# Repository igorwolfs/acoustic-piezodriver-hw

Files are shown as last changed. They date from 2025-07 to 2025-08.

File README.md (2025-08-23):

# Acoustic Piezodriver HW

This board generates the signal used to excite the piezo-module. Excitation frequencies are between 100 kHz and 10 MHz. All above 5 MHz will probably be hard to reach, given the component specs had to be balanced with price.

## 40V BOOST
Supplies the single-phase inverter with a 40 V voltage, given a 20 V input voltage.

## 6V SEPIC
Supplies around 6 V to the PCONN 5V connector. Meant to supply power to the acoustic-processing-hw board.

## 10 V SEPIC
Supplies the FET-drivers with a steady 10V.

## SIGCONN
Drives the PWM signals, enables the 40V BOOST and the 10V SEPIC, contains an SPI bus meant to control the on-board ADC and temperature sensors. Meant to be connected to the acoustic-processing-hw board.

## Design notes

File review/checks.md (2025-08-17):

# Component Checks
## I2C bus connection
- Are all I2C bus signals connected to the output

## Footprints
- Are all footprints
	- Corresponding to the footprint in the datasheet
	- Is the actual component the right one (right capacitance / resistance / LCSC PN)

## Temperature Sensor
- Check the plane requirements below the sensor.

## Connectors
- Check connector orientation 
- Check connector distance from edge
- Check connector footprint

## Footprints
- Check whether footprints 

# Capacitors
## C1 / C2 bootstrap caps
- 220 nF OK -> 
-

## Filtering caps
- 220 nF? Why so large?

# IC's
## Switching IC
10 V sepic
- Impedance: 39 kOhm

# Layout Checks
## Positioning 
- Check whether feedback resistors for DC-DC converters are easily replaceable if needed
- Check if there's measurement points at the input

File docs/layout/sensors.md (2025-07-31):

# Temperature sensor

- Put a copper plane between the heat-source and draw it until underneath the sensor

# ADC
- Make sure the traces between the HAL-sensors and the ADC are not routed across a too noisy area.
	- Although impedance is honestly pretty low

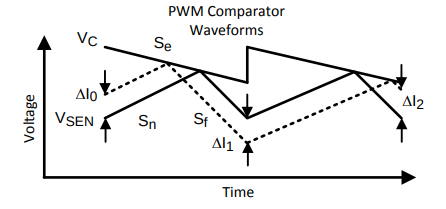
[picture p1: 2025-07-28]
docs/schematic/dcdc-converters/images/LM3478_subharmonic.png

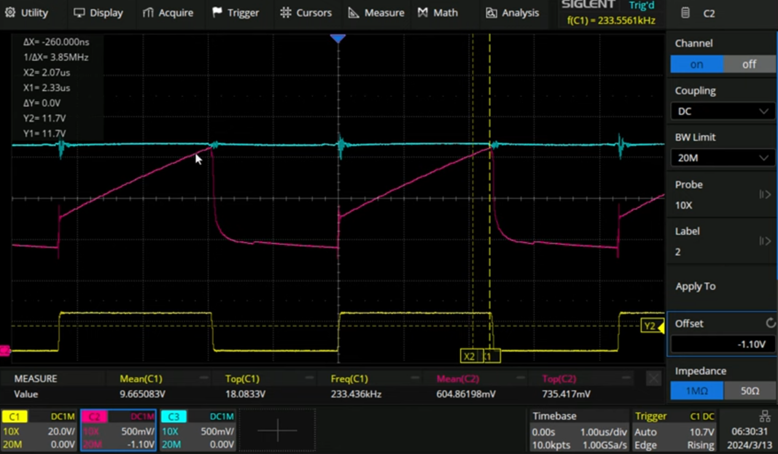
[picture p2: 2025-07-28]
docs/schematic/dcdc-converters/images/peak_current_mode_control.png

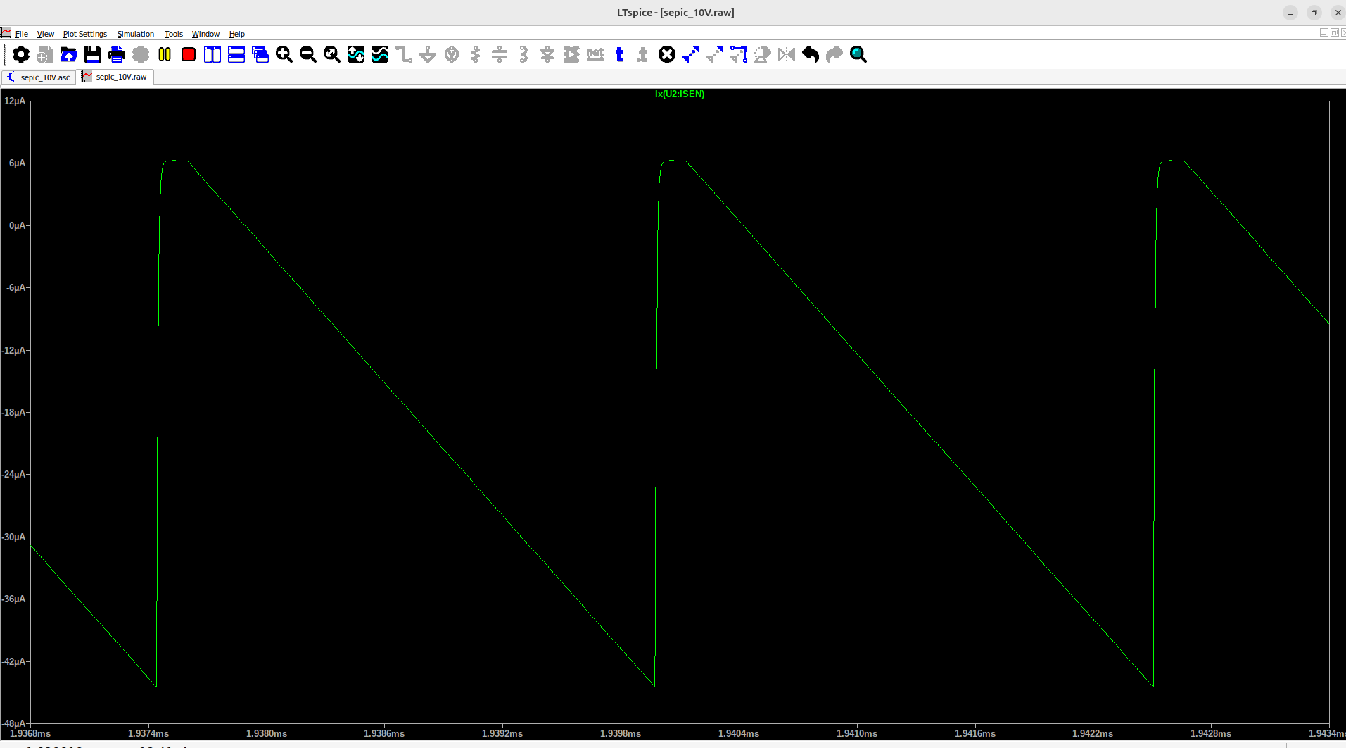
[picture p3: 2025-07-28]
docs/schematic/dcdc-converters/images/LM3478_Isense_nocomp.png

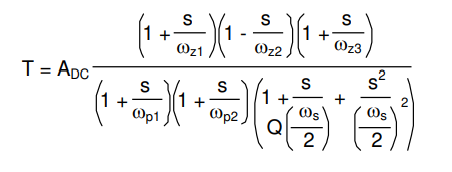
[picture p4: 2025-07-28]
docs/schematic/dcdc-converters/boost_converter/control_tot.png

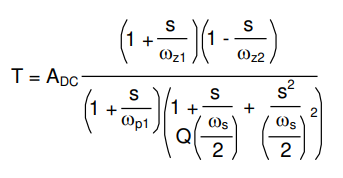
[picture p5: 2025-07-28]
docs/schematic/dcdc-converters/boost_converter/control_co.png

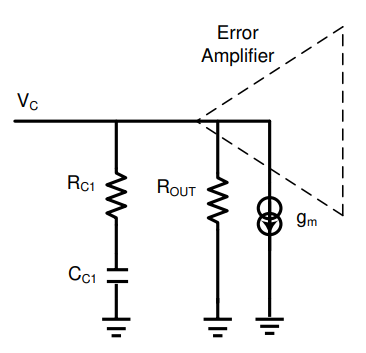
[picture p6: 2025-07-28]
docs/schematic/dcdc-converters/boost_converter/control_ea.png

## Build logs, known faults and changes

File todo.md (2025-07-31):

# Schematics
## DC-DC Converters
- Add 1 x LM3478 (doesn't require level-shifting circuitry)
	- Boost converter: to bring a voltage of between 15-20 volts up to 40 V ()
- Add 1 x SEPIC converter for the level-shifting FET drivers
- Add 1 x SEPIC-converter for the 5 V power supply

### Goal
- We want to be able to adapt the driving voltage dynamically
	- The boost converter will need to drive the voltage to up to 40 volts
		- It however might have 9-10 volts connected
		- There should be a bypass from the boost converter VBAT directly to the inverted driving circuit as well
			- This way we can drive the piezo with voltages as low as 5 Vpp
	- The level shifter will need to continuously be at 10 volts.
		- It however might have 9-10 V connected
- We want to avoid working with variable resistors

#### Boost converter (5-20 V -> 5-40 V)
- Input: between 5 and 20 volts
	- If < 10 volts: make sure you have bypass circuitry that allows you to directly drive the inverter from your source
	- If > 10 volts: make sure you have some-kind of soldering bridge or short that you can eliminate to force all current through the boost converter.
		- Add a spot for a feedback resistor slope compensation (in case D > 0.5)
- Output: between 5 V and 40 V
- Currents: max 10 amps RMS at 40 V

**Bypass** 
- Create a bypass for the boost converter (e.g.: simply 0-ohm high power resistor, or solderbridge) whenever you want to use pure battery voltage
- When you want to use a voltage unreachable by your power supply (e.g.: 40 V)
	- Make sure to use a boost converter, and set the input voltage between 10-20 Volts (to limit the stress on the passives)

## ADC Measurement
- Add a 4-channel ADC 
	- (2 inputs) Differential channel to measure current going to the piezo
	- 1 input: Current going to the ADC
	- 1 input: Total voltage (use a resistive divider)
		- Based on this one can activate SEPICs
	- 1 input: Total current draw (use a resistor)
- Add front-end (RC-filter at cutoff below 1 kHz for noise purpoes)
- Add hall-sensor for in-circuit current measurement
- Add a voltage divider so 
	- Vbat: (0, 25) -> (0->2.048)

## Temperature Sensors
- 2 different addresses
- Communication over I2C

## I2C bus checks
- Check if total capacitance on the I2C bus isn't too large
- I2C ADC-bus
- 2xI2C temperature sensors

## Connectors
- Add pads for each power supply so you can supply it externally for testing if necessary
	- For 6V no pad is required since there is already a hal-sensor that takes in the current.

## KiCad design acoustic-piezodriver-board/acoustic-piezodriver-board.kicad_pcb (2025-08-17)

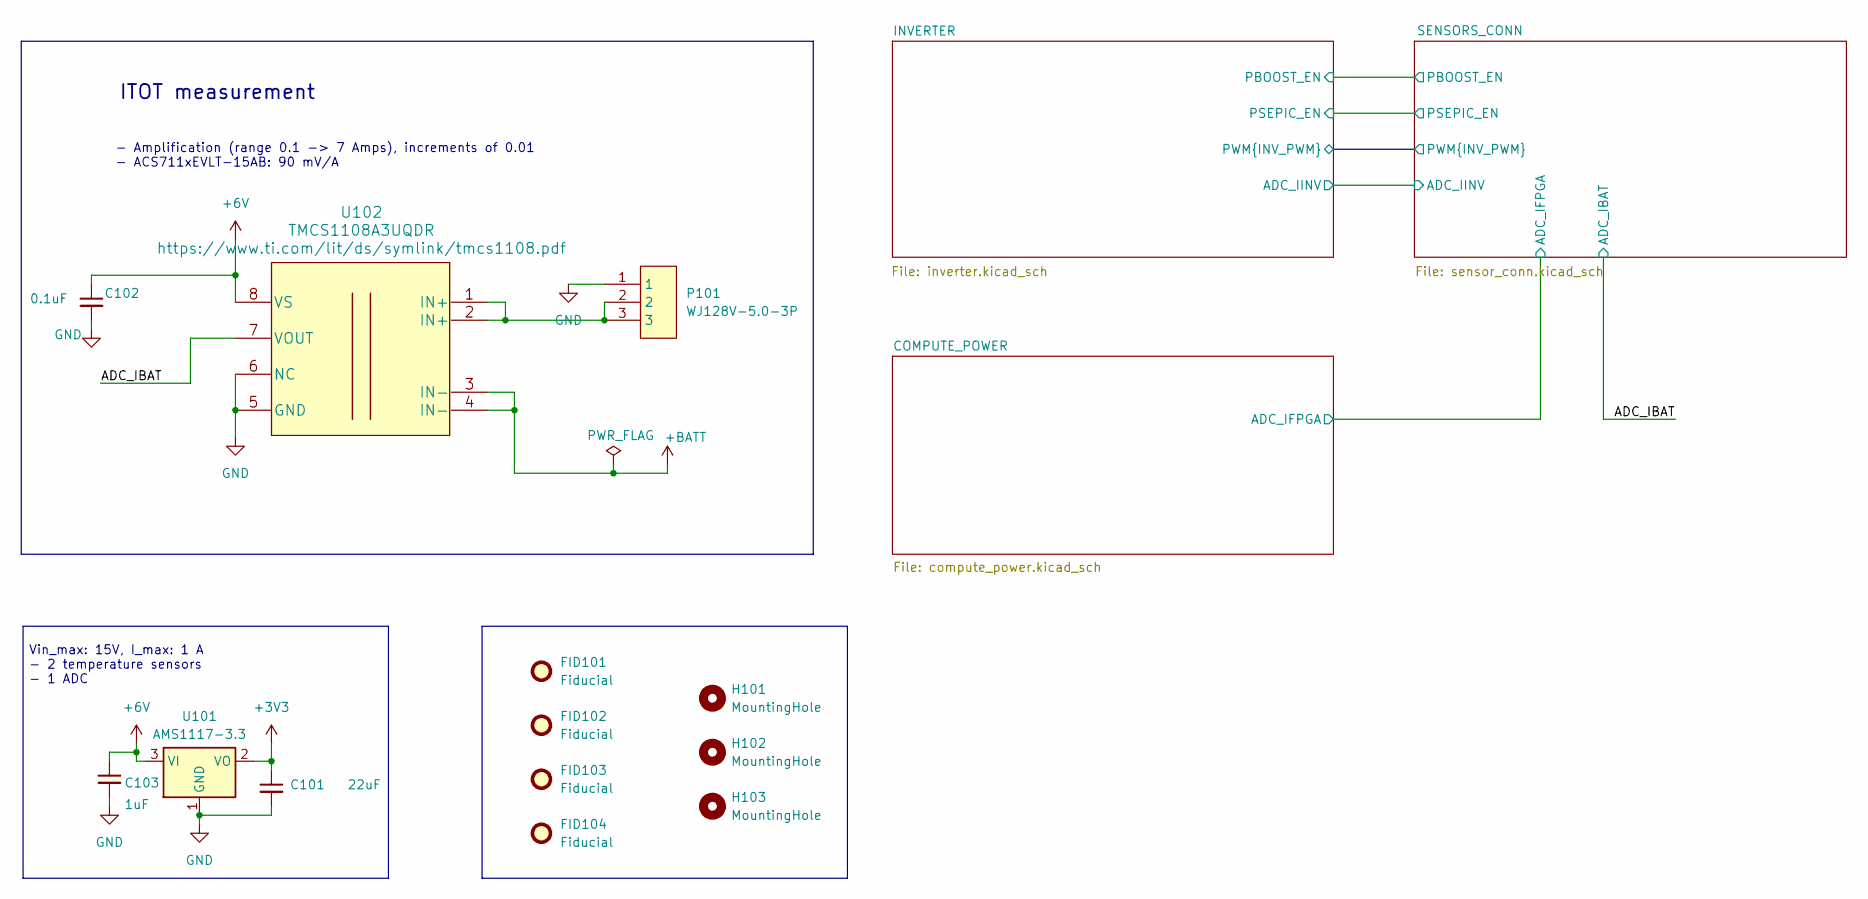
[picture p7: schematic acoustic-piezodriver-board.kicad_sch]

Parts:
C101: 22uF; C_0805_2012Metric; Manufacturing Part Numb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 CL21A226MAQNNNE; LCSC Part Number C45783
C102: 0.1uF; C_0402_1005Metric; Manufacturing Part Numb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 CL05B104KB54PNC; LCSC Part Number C307331
C103: 1uF; C_0805_2012Metric; Manufacturing Part Numb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 CL21B105KBFNNNE; LCSC Part Number C28323
FID101, FID102, FID103, FID104: Fiducial; Fiducial_1mm_Mask2mm
H101, H102, H103: MountingHole; ToolingHole_1.152mm
P101: WJ128V-5.0-3P; Manufacturing Part Numb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 WJ128V-5.0-3P; LCSC Part Number C8270
U101: AMS1117-3.3; SOT-223-3_TabPin2; Manufacturing Part Numb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 AMS1117-3.3; LCSC Part Number C6186
U102: TMCS1108A3UQDR; Manufacturing Part Numb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 TMCS1108A3UQDR; LCSC Part Number C3684263

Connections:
+3V3: C101.1, U101.2 (VO); also elsewhere on the board
+6V: C102.1, C103.1, U101.3 (VI), U102.8 (VS); also elsewhere on the board
+BATT: U102.3 (IN-), U102.4 (IN-); also elsewhere on the board
/ADC_IBAT: U102.7 (VOUT); also elsewhere on the board
GND: C101.2, C102.2, C103.2, P101.1, U101.1 (GND), U102.5 (GND), U102.6 (NC); also elsewhere on the board
unnamed: P101.2, P101.3, U102.1 (IN+), U102.2 (IN+)

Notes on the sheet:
ITOT measurement
- Amplification (range 0.1 -> 7 Amps), increments of 0.01 - ACS711xEVLT-15AB: 90 mV/A
Vin_max: 15V, I_max: 1 A - 2 temperature sensors - 1 ADC

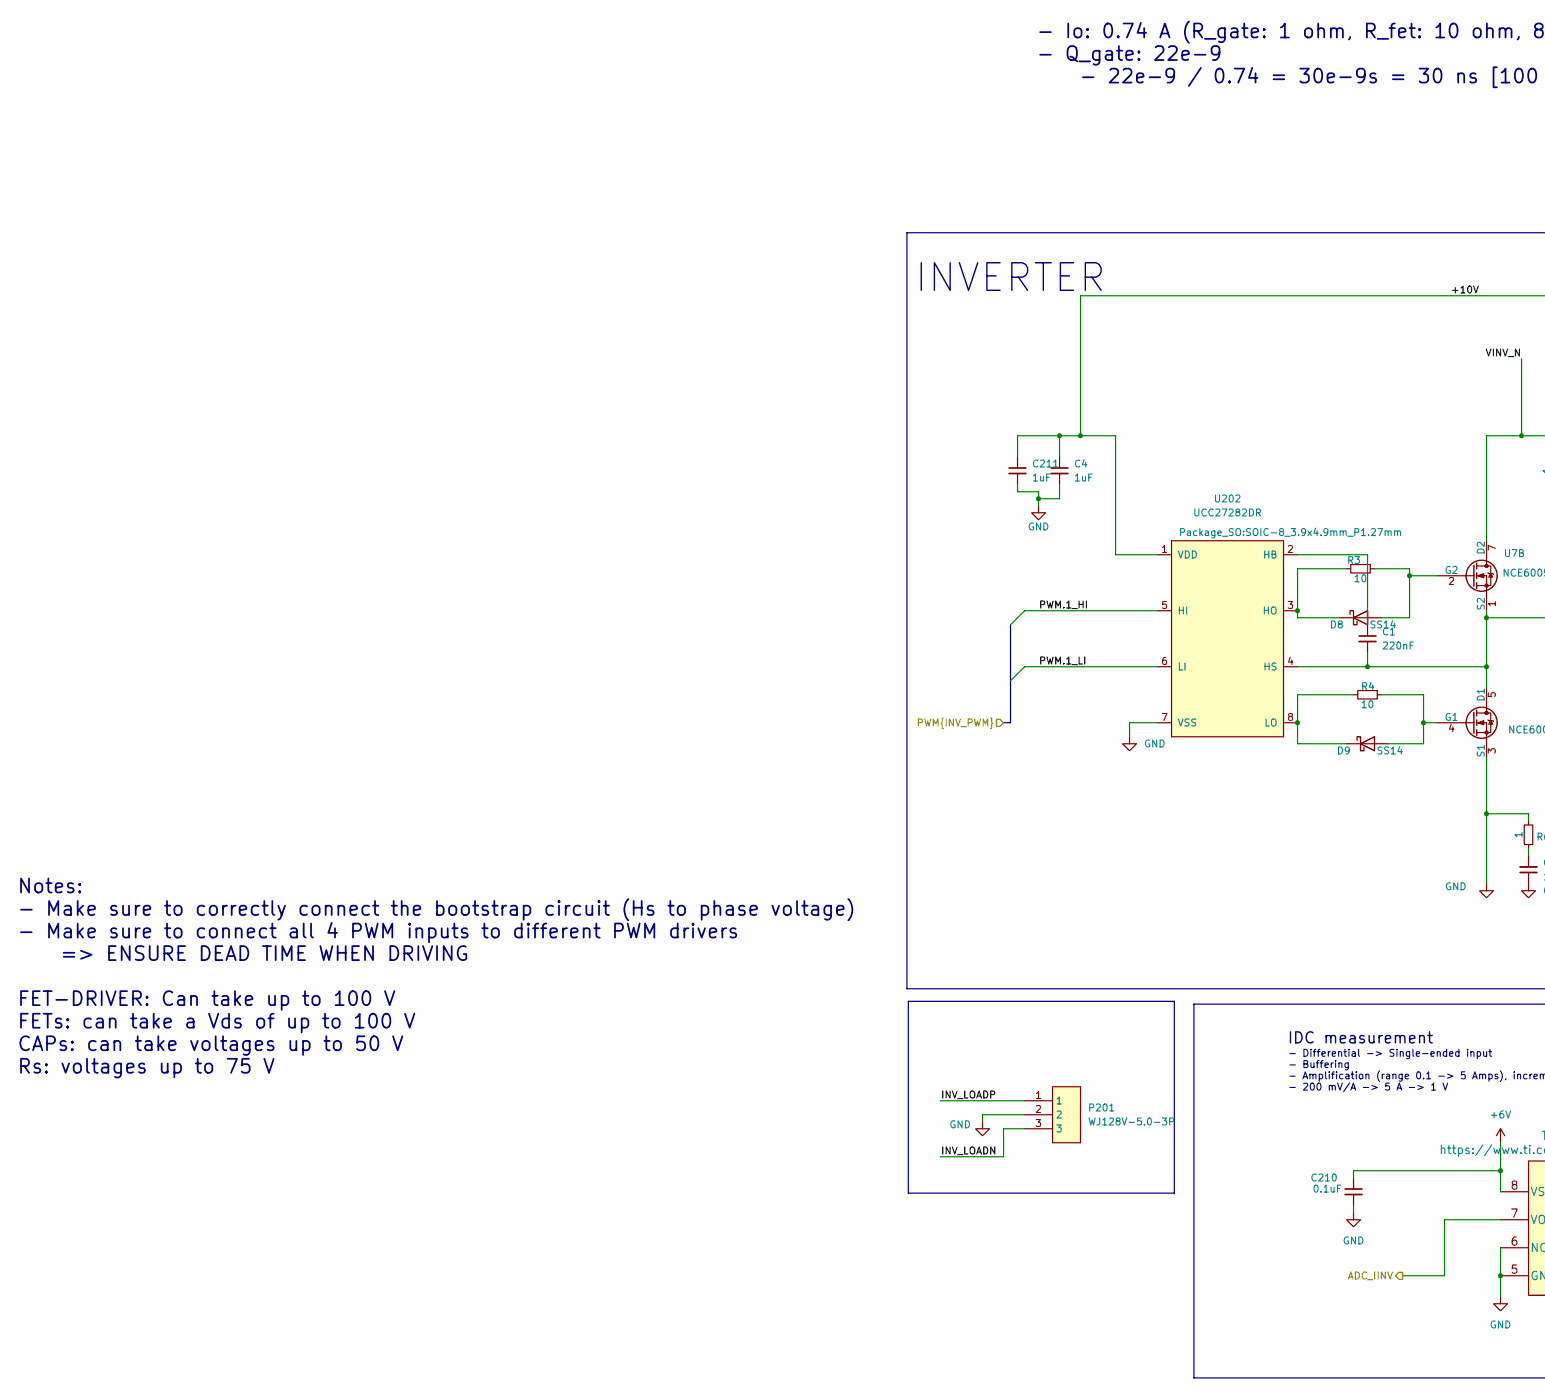
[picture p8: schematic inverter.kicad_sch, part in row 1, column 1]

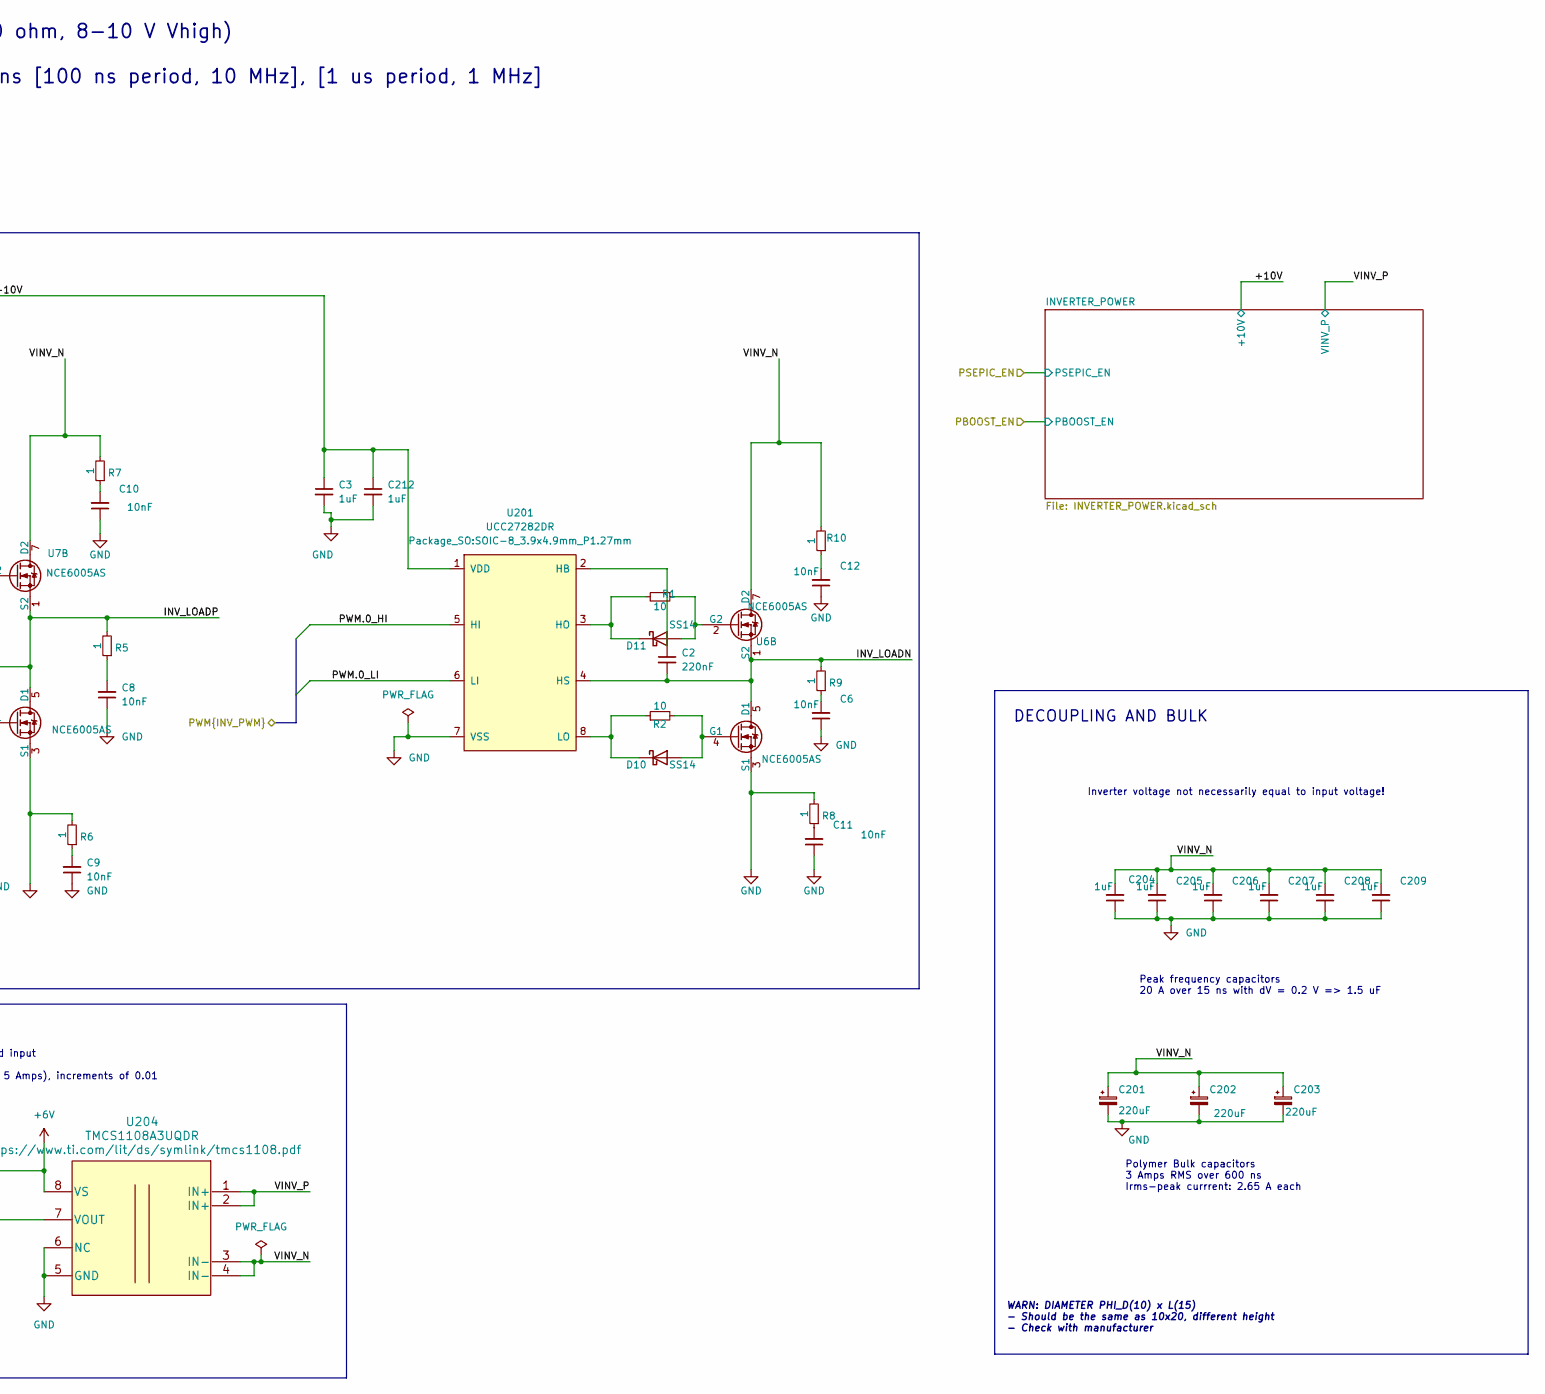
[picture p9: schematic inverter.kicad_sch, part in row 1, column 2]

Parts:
C1, C2: 220nF; C_0805_2012Metric; Manufacturing Part Numb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 CL21B224KBFNNNE; LCSC Part Number C5378
C3, C4, C204, C205, C206, C207, C208, C209, C211, C212: 1uF; C_0805_2012Metric; Manufacturing Part Numb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 CL21B105KBFNNNE; LCSC Part Number C28323
C6, C8, C9, C10, C11, C12: 10nF; C_0402_1005Metric; Manufacturing Part Numb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 CL05B103KB5NNNC; LCSC Part Number C15195
C201, C202, C203: 220uF; C_Radial_D10.0mm_H16.0mm_P5.00mm; Manufacturing Part Numb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 SPZ1JM221G15O00RAXXX; LCSC Part Number C2983797
C210: 0.1uF; C_0402_1005Metric; Manufacturing Part Numb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 CL05B104KB54PNC; LCSC Part Number C307331
D8, D9, D10, D11: SS14; D_SMA; Manufacturing Part Numb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 SS14; LCSC Part Number C2480
P201: WJ128V-5.0-3P; Manufacturing Part Numb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 WJ128V-5.0-3P; LCSC Part Number C8270
R1, R2, R3, R4: 10; R_1206_3216Metric; Manufacturing Part Numb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 1206W4F100JT5E; LCSC Part Number C17903
R5, R6, R7, R8, R9, R10: 1; R_0603_1608Metric; Manufacturing Part Numb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 0603WAF100KT5E; LCSC Part Number C22936
U6, U7: NCE6005AS; SOIC-8_3.9x4.9mm_P1.27mm; Manufacturing Part Numb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 NCE6005AS; LCSC Part Number C126151
U201, U202: UCC27282DR; SOIC-8_3.9x4.9mm_P1.27mm; Manufacturing Part Numb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 UCC27282DR; LCSC Part Number C2867844
U204: TMCS1108A3UQDR; Manufacturing Part Numb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 TMCS1108A3UQDR; LCSC Part Number C3684263

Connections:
+6V: C210.1, U204.8 (VS); also elsewhere on the board
/INVERTER/+10V: C3.1, C4.1, C211.1, C212.1, U201.1 (VDD), U202.1 (VDD); also elsewhere on the board
/INVERTER/ADC_IINV: U204.7 (VOUT); also elsewhere on the board
/INVERTER/INV_LOADN: C2.2, P201.3, R9.2, U6.1 (S2), U6.5 (D1), U6.6 (D1), U201.4 (HS)
/INVERTER/INV_LOADP: C1.2, P201.1, R5.2, U7.1 (S2), U7.5 (D1), U7.6 (D1), U202.4 (HS)
/INVERTER/PWM.0_HI: U201.5 (HI); also elsewhere on the board
/INVERTER/PWM.0_LI: U201.6 (LI); also elsewhere on the board
/INVERTER/PWM.1_HI: U202.5 (HI); also elsewhere on the board
/INVERTER/PWM.1_LI: U202.6 (LI); also elsewhere on the board
/INVERTER/VINV_N: C201.1, C202.1, C203.1, C204.2, C205.2, C206.2, C207.2, C208.2, C209.2, R7.2, R10.2, U6.7 (D2), U6.8 (D2), U7.7 (D2), U7.8 (D2), U204.3 (IN-), U204.4 (IN-)
/INVERTER/VINV_P: U204.1 (IN+), U204.2 (IN+); also elsewhere on the board
GND: C3.2, C4.2, C6.1, C8.1, C9.1, C10.1, C11.1, C12.1, C201.2, C202.2, C203.2, C204.1, C205.1, C206.1, C207.1, C208.1, C209.1, C210.2, C211.2, C212.2, P201.2, R6.2, R8.2, U6.3 (S1), U7.3 (S1), U201.7 (VSS), U202.7 (VSS), U204.5 (GND), U204.6 (NC); also elsewhere on the board
unnamed: C6.2, R9.1
unnamed: C8.2, R5.1
unnamed: C9.2, R6.1
unnamed: C10.2, R7.1
unnamed: C11.2, R8.1
unnamed: C12.2, R10.1
unnamed: D8.2 (A), R3.1, U7.2 (G2)
unnamed: D8.1 (K), R3.2, U202.3 (HO)
unnamed: D9.2 (A), R4.1, U7.4 (G1)
unnamed: D9.1 (K), R4.2, U202.8 (LO)
unnamed: D10.2 (A), R2.2, U6.4 (G1)
unnamed: D10.1 (K), R2.1, U201.8 (LO)
unnamed: D11.2 (A), R1.1, U6.2 (G2)
unnamed: D11.1 (K), R1.2, U201.3 (HO)
unnamed: C2.1, U201.2 (HB)
unnamed: C1.1, U202.2 (HB)

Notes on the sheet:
- Io: 0.74 A (R_gate: 1 ohm, R_fet: 10 ohm, 8-10 V Vhigh) - Q_gate: 22e-9 - 22e-9 / 0.74 = 30e-9s = 30 ns [100 ns period, 10 MHz], [1 us period, 1 MHz]
DECOUPLING AND BULK
INVERTER
Peak frequency capacitors 20 A over 15 ns with dV = 0.2 V => 1.5 uF
- Differential -> Single-ended input - Buffering - Amplification (range 0.1 -> 5 Amps), increments of 0.01 - 200 mV/A -> 5 A -> 1 V
Notes: - Make sure to correctly connect the bootstrap circuit (Hs to phase voltage) - Make sure to connect all 4 PWM inputs to different PWM drivers => ENSURE DEAD TIME WHEN DRIVING FET-DRIVER: Can take up to 100 V FETs: can take a Vds of up to 100 V CAPs: can take voltages up to 50 V Rs: voltages 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
Polymer Bulk capacitors 3 Amps RMS over 600 ns Irms-peak currrent: 2.65 A each
Inverter voltage not necessarily equal to input voltage!
WARN: DIAMETER PHI_D(10) x L(15) - Should be the same as 10x20, different height - Check with manufacturer
IDC measurement

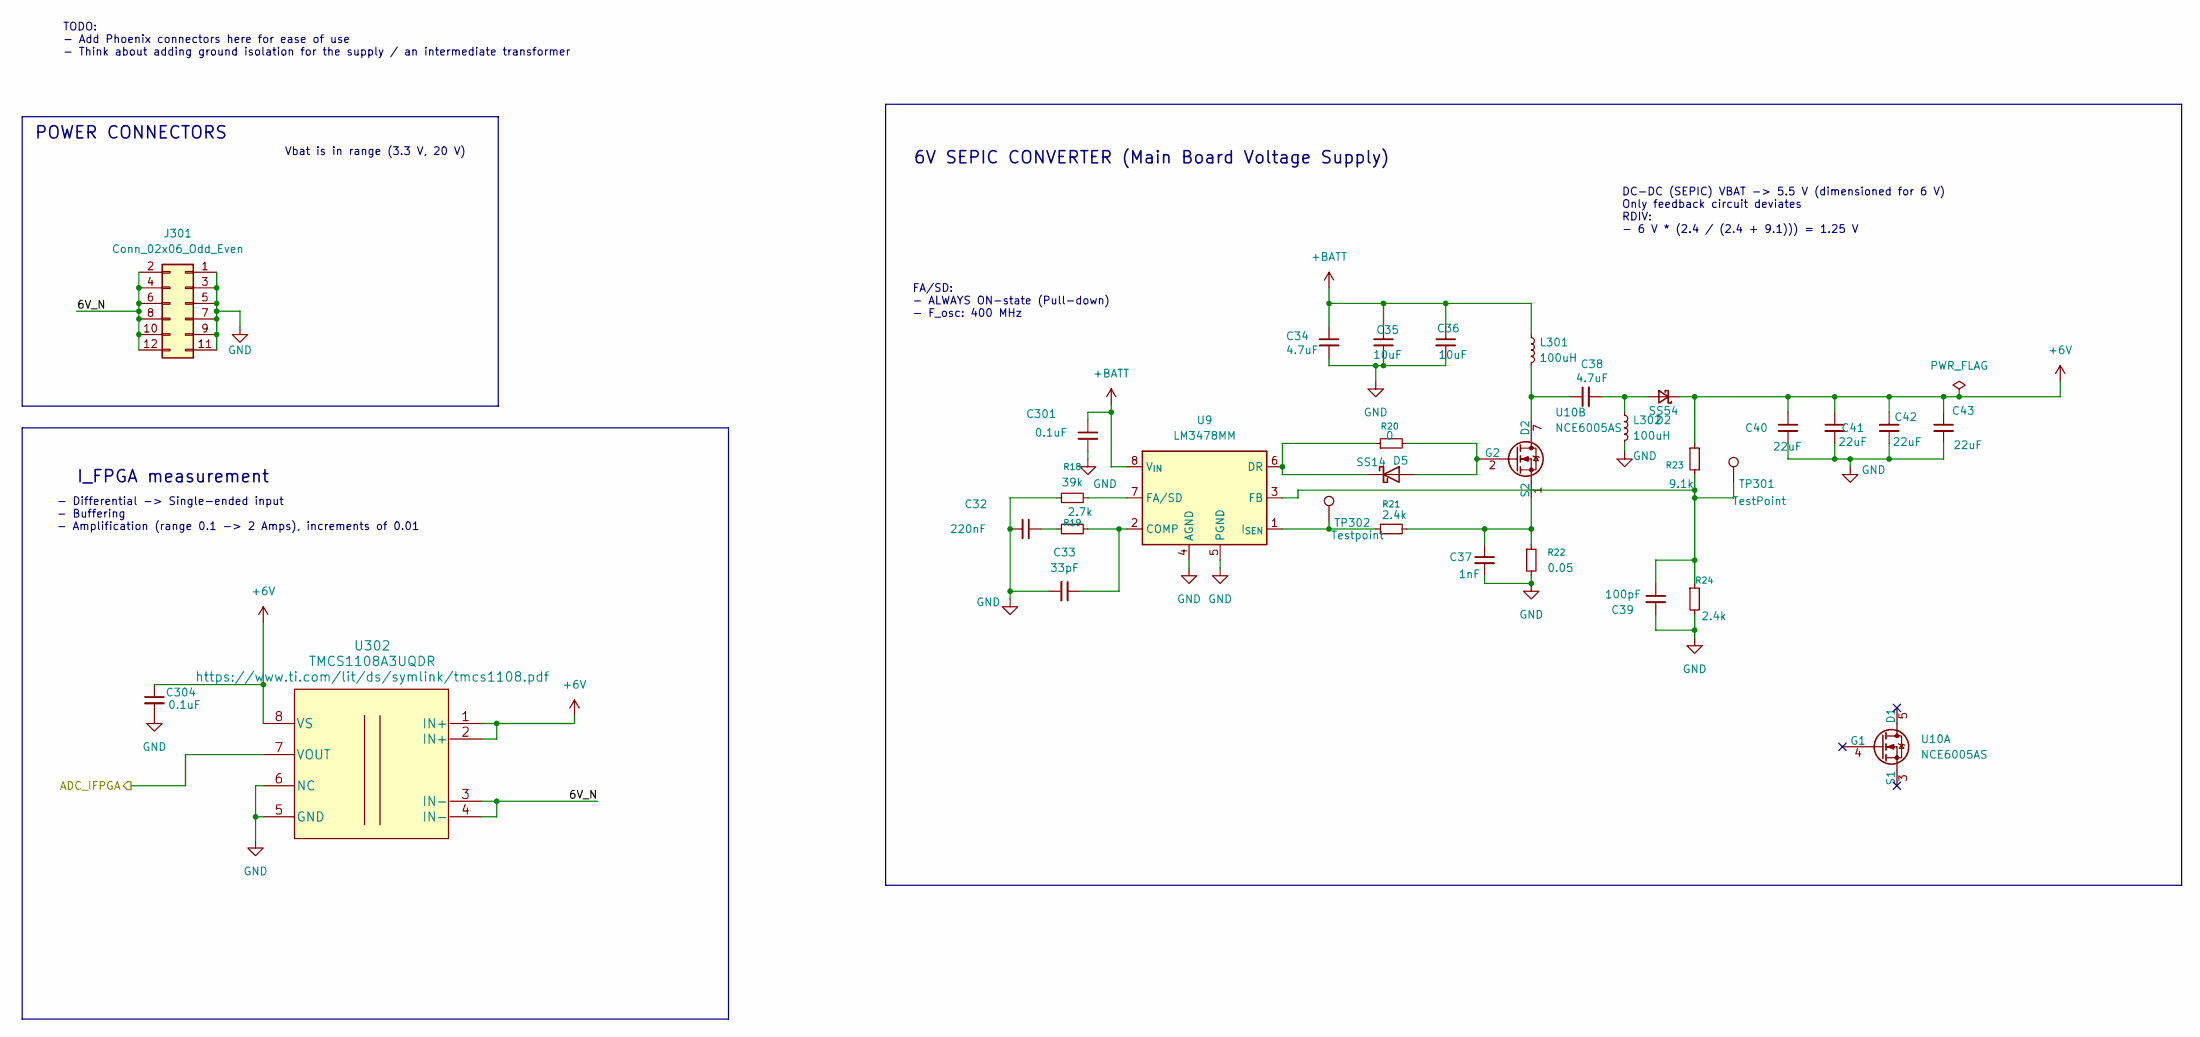
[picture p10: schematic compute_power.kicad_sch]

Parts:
C32: 220nF; C_0805_2012Metric; Manufacturing Part Numb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 CL21B224KBFNNNE; LCSC Part Number C5378
C33: 33pF; C_0603_1608Metric; Manufacturing Part Numb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 CL10C330JB8NNNC; LCSC Part Number C1663
C34, C38: 4.7uF; C_1206_3216Metric; Manufacturing Part Numb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 1206B475K500NT; LCSC Part Number C29823
C35, C36: 10uF; C_0805_2012Metric; Manufacturing Part Numb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 GRM21BR61H106KE43L; LCSC Part Number C440198
C37: 1nF; C_0402_1005Metric; Manufacturing Part Numb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 0402B102K500NT; LCSC Part Number C1523
C39: 100pF; C_0402_1005Metric; Manufacturing Part Numb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 0402CG101J500NT; LCSC Part Number C1546
C40, C41, C42, C43: 22uF; C_0805_2012Metric; Manufacturing Part Numb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 CL21A226MAQNNNE; LCSC Part Number C45783
C301, C304: 0.1uF; C_0402_1005Metric; Manufacturing Part Numb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 CL05B104KB54PNC; LCSC Part Number C307331
D2: SS54; D_SMA; Manufacturing Part Numb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 SS54; LCSC Part Number C22452
D5: SS14; D_SMA; Manufacturing Part Numb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 SS14; LCSC Part Number C2480
J301: Conn_02x06_Odd_Even; PinHeader_2x06_P2.54mm_Vertical; Manufacturing Part Numb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 B-2100S12P-B110; LCSC Part Number C124388
L301, L302: 100uH; PSPMAA1050H-101M-ANP; Manufacturing Part Numb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 PSPMAA1050H-101M-ANP; LCSC Part Number C5273830
R18: 39k; R_0603_1608Metric; Manufacturing Part Numb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 0603WAF3902T5E; LCSC Part Number C23153
R19: 2.7k; R_0603_1608Metric; Manufacturing Part Numb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 0603WAF2701T5E; LCSC Part Number C13167
R20: 0; R_0603_1608Metric_Pad0.98x0.95mm_HandSolder; Manufacturing Part Numb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 0603WAJ0000T5E; LCSC Part Number C15402
R21: 2.4k; R_0805_2012Metric_Pad1.20x1.40mm_HandSolder; Manufacturing Part Numb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 0805W8F2401T5E; LCSC Part Number C17526
R22: 0.05; R_1206_3216Metric_Pad1.30x1.75mm_HandSolder; Manufacturing Part Numb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 1206W3F500MT5E; LCSC Part Number C127691
R23: 9.1k; R_0603_1608Metric; Manufacturing Part Numb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 0603WAF9101T5E; LCSC Part Number C23260
R24: 2.4k; R_0603_1608Metric; Manufacturing Part Numb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 0603WAF2401T5E; LCSC Part Number C22940
TP301: TestPoint; TestPoint_Pad_D1.0mm
TP302: Testpoint; TestPoint_Pad_D1.0mm
U9: LM3478MM; VSSOP-8_3x3mm_P0.65mm; Manufacturing Part Numb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 LM3478MMX/NOPB; LCSC Part Number C404045
U10: NCE6005AS; SOIC-8_3.9x4.9mm_P1.27mm; Manufacturing Part Numb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 NCE6005AS; LCSC Part Number C126151
U302: TMCS1108A3UQDR; Manufacturing Part Numb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 TMCS1108A3UQDR; LCSC Part Number C3684263

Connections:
+6V: C40.1, C41.1, C42.1, C43.1, C304.1, D2.1 (K), R23.1, U302.1 (IN+), U302.2 (IN+), U302.8 (VS); also elsewhere on the board
+BATT: C34.1, C35.1, C36.1, C301.1, L301.1, U9.8 (V_{IN}); also elsewhere on the board
/COMPUTE_POWER/6V_N: J301.2, J301.4, J301.6, J301.8, J301.10, J301.12, U302.3 (IN-), U302.4 (IN-)
/COMPUTE_POWER/ADC_IFPGA: U302.7 (VOUT); also elsewhere on the board
GND: C32.2, C33.2, C34.2, C35.2, C36.2, C37.2, C39.2, C40.2, C41.2, C42.2, C43.2, C301.2, C304.2, J301.1, J301.3, J301.5, J301.7, J301.9, J301.11, L302.2, R18.1, R22.2, R24.2, U9.4 (AGND), U9.5 (PGND), U302.5 (GND), U302.6 (NC); also elsewhere on the board
unnamed: C32.1, R19.1
unnamed: C38.1, L301.2, U10.7 (D2), U10.8 (D2)
unnamed: C38.2, D2.2 (A), L302.1
unnamed: D5.2 (A), R20.2, U10.2 (G2)
unnamed: D5.1 (K), R20.1, U9.6 (DR)
unnamed: C33.1, R19.2, U9.2 (COMP)
unnamed: R18.2, U9.7 (FA/SD)
unnamed: C39.1, R23.2, R24.1, TP301.1, U9.3 (FB)
unnamed: R21.1, TP302.1, U9.1 (I_{SEN})
unnamed: C37.1, R21.2, R22.1, U10.1 (S2)

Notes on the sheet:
POWER CONNECTORS
I_FPGA measurement
DC-DC (SEPIC) VBAT -> 5.5 V (dimensioned for 6 V) Only feedback circuit deviates RDIV: - 6 V * (2.4 / (2.4 + 9.1))) = 1.25 V
Vbat is in range (3.3 V, 20 V)
- Differential -> Single-ended input - Buffering - Amplification (range 0.1 -> 2 Amps), increments of 0.01
6V SEPIC CONVERTER (Main Board Voltage Supply)
TODO: - Add Phoenix connectors here for ease of use - Think about adding ground isolation for the supply / an intermediate transformer
FA/SD: - ALWAYS ON-state (Pull-down) - F_osc: 400 MHz

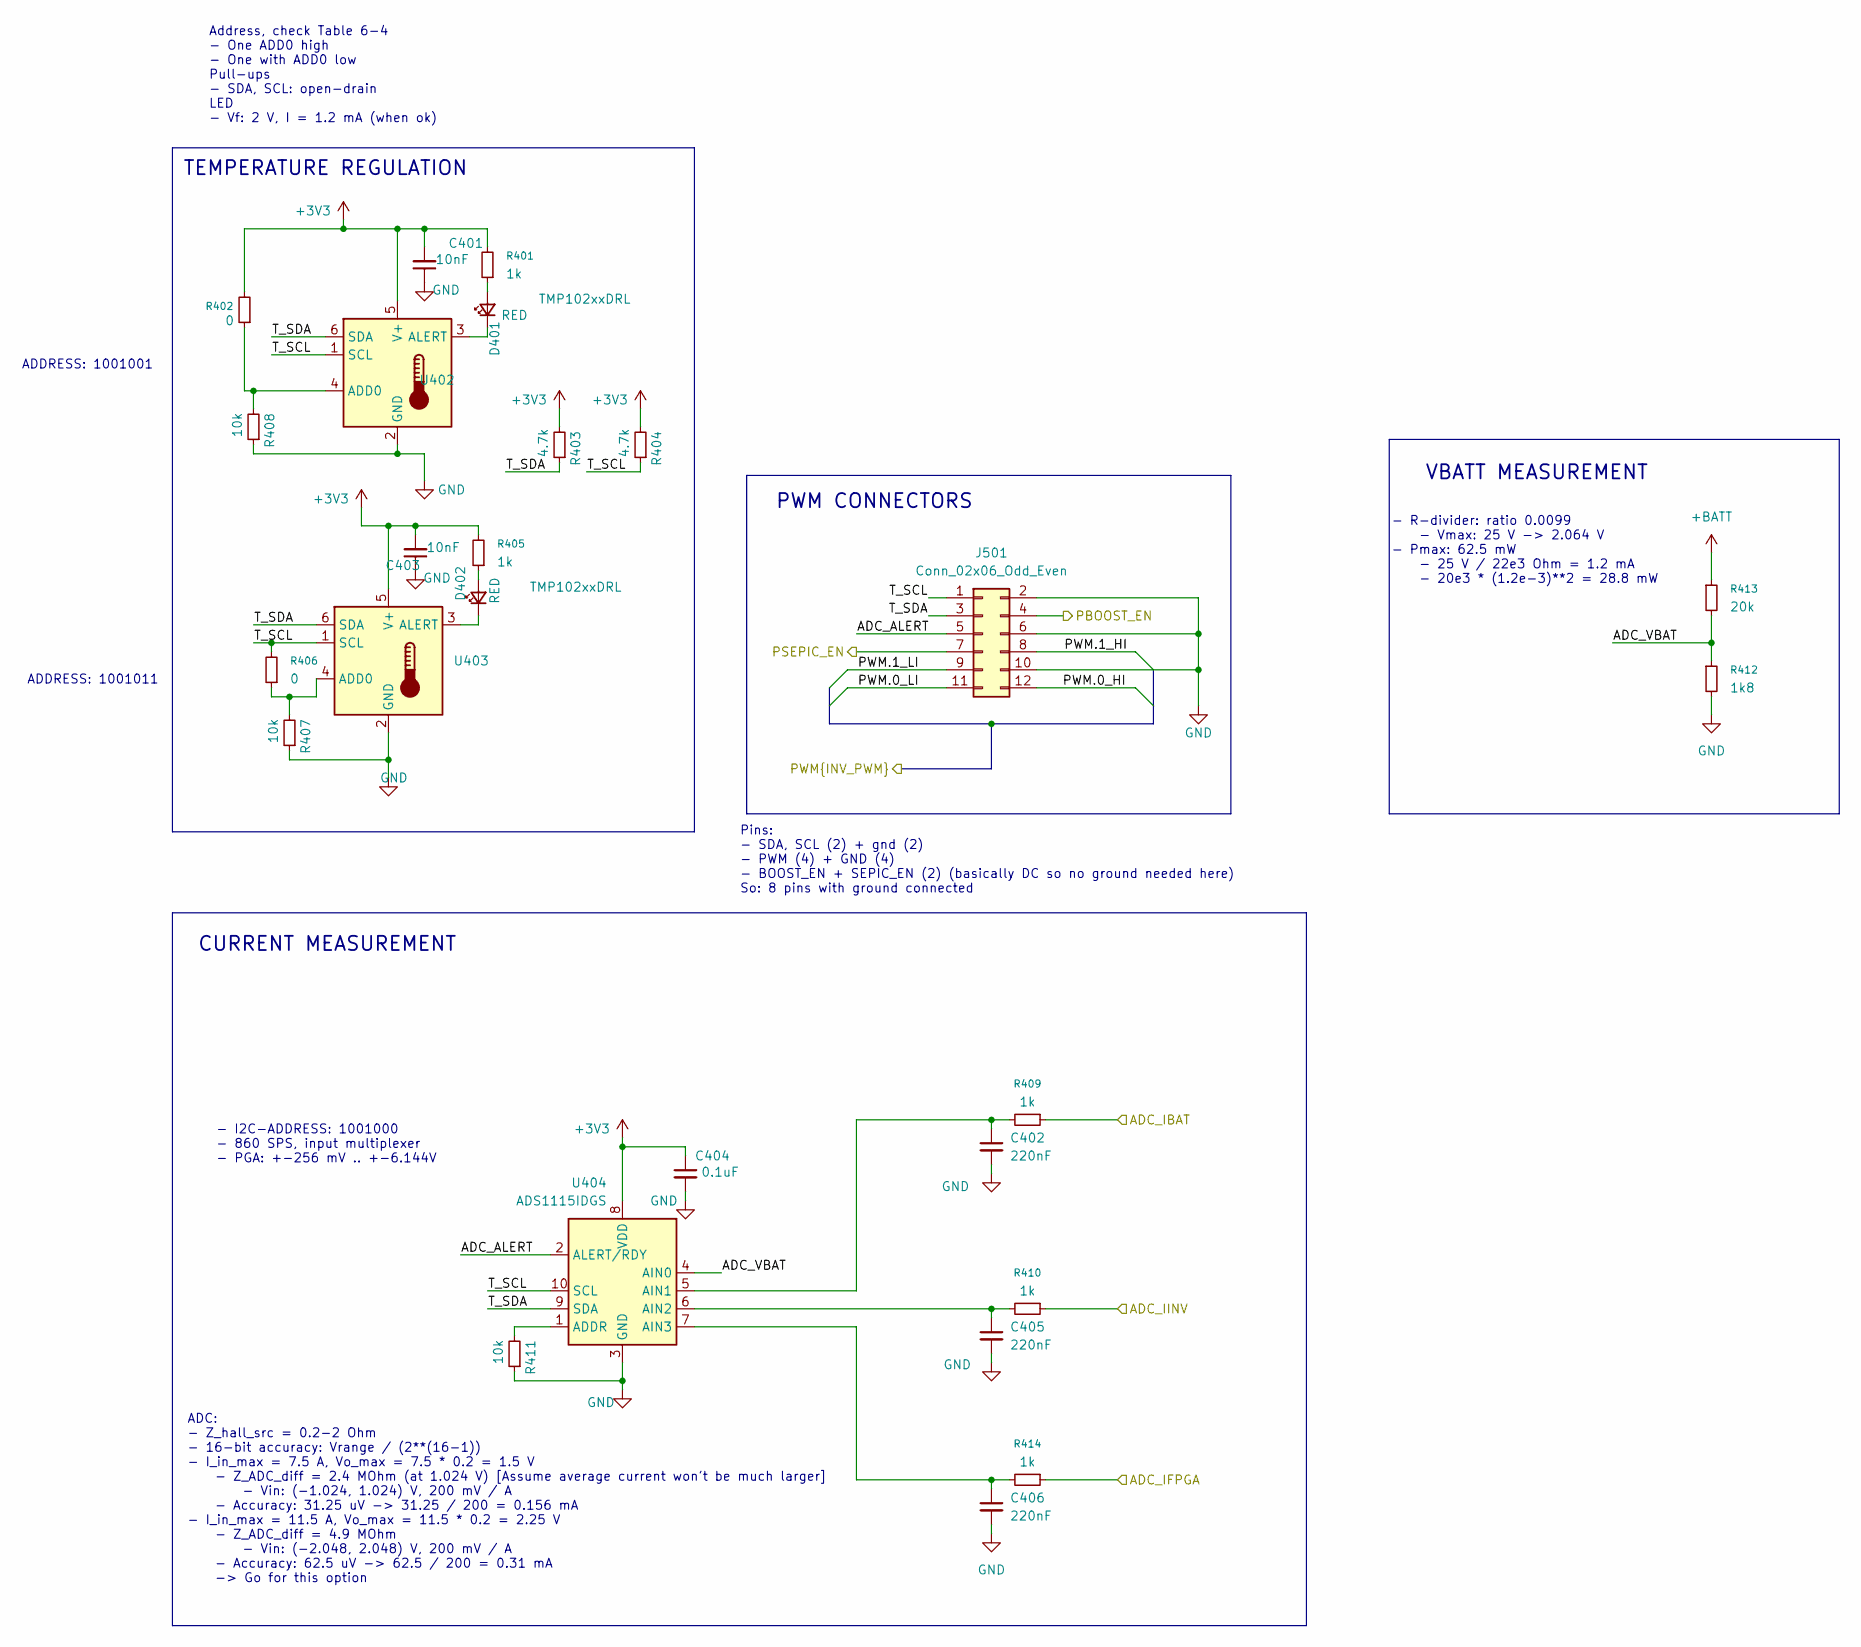
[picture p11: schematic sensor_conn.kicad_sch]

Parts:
C401, C403: 10nF; C_0402_1005Metric; Manufacturing Part Numb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 CL05B103KB5NNNC; LCSC Part Number C15195
C402, C405, C406: 220nF; C_0402_1005Metric; Manufacturing Part Numb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 CL05B224KO5NNNC; LCSC Part Number C16772
C404: 0.1uF; C_0402_1005Metric; Manufacturing Part Numb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 CL05B104KB54PNC; LCSC Part Number C307331
D401, D402: RED; LED_0603_1608Metric; Manufacturing Part Numb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 KT-0603R; LCSC Part Number C2286
J501: Conn_02x06_Odd_Even; PinHeader_2x06_P2.54mm_Vertical; Manufacturing Part Numb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 B-2100S12P-B110; LCSC Part Number C124388
R401, R405, R409, R410, R414: 1k; R_0402_1005Metric; Manufacturing Part Numb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 0402WGF1001TCE; LCSC Part Number C11702
R402, R406: 0; R_0603_1608Metric_Pad0.98x0.95mm_HandSolder; Manufacturing Part Numb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 0603WAJ0000T5E; LCSC Part Number C15402
R403, R404: 4.7k; R_0402_1005Metric; Manufacturing Part Numb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 0402WGF4701TCE; LCSC Part Number C25900
R407, R408, R411: 10k; R_0603_1608Metric; Manufacturing Part Numb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 0603WAJ0103T5E; LCSC Part Number C15401
R412: 1k8; R_0603_1608Metric; Manufacturing Part Numb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 0603WAF1801T5E; LCSC Part Number C4177
R413: 20k; R_0402_1005Metric; Manufacturing Part Numb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 0402WGF2002TCE; LCSC Part Number C25765
U402, U403: TMP102xxDRL; SOT-563; Manufacturing Part Numb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 TMP102AIDRLR; LCSC Part Number C99269
U404: ADS1115IDGS; TSSOP-10_3x3mm_P0.5mm; Manufacturing Part Numb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 ADS1115IDGSR; LCSC Part Number C37593

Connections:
+3V3: C401.2, C403.2, C404.1, R401.2, R402.2, R403.2, R404.2, R405.2, U402.5 (V+), U403.5 (V+), U404.8 (VDD); also elsewhere on the board
+BATT: R413.1; also elsewhere on the board
/ADC_IBAT: R409.1; also elsewhere on the board
/COMPUTE_POWER/ADC_IFPGA: R414.1; also elsewhere on the board
/INVERTER/ADC_IINV: R410.1; also elsewhere on the board
/INVERTER/PBOOST_EN: J501.4; also elsewhere on the board
/INVERTER/PSEPIC_EN: J501.7; also elsewhere on the board
/INVERTER/PWM.0_HI: J501.12; also elsewhere on the board
/INVERTER/PWM.0_LI: J501.11; also elsewhere on the board
/INVERTER/PWM.1_HI: J501.8; also elsewhere on the board
/INVERTER/PWM.1_LI: J501.9; also elsewhere on the board
/SENSORS_CONN/ADC_ALERT: J501.5, U404.2 (ALERT/RDY)
/SENSORS_CONN/ADC_VBAT: R412.1, R413.2, U404.4 (AIN0)
/SENSORS_CONN/T_SCL: J501.1, R404.1, R406.2, U402.1 (SCL), U403.1 (SCL), U404.10 (SCL)
/SENSORS_CONN/T_SDA: J501.3, R403.1, U402.6 (SDA), U403.6 (SDA), U404.9 (SDA)
GND: C401.1, C402.2, C403.1, C404.2, C405.2, C406.2, J501.2, J501.6, J501.10, R407.1, R408.1, R411.1, R412.2, U402.2 (GND), U403.2 (GND), U404.3 (GND); also elsewhere on the board
unnamed: D401.2 (A), R401.1
unnamed: D401.1 (K), U402.3 (ALERT)
unnamed: D402.2 (A), R405.1
unnamed: D402.1 (K), U403.3 (ALERT)
unnamed: R402.1, R408.2, U402.4 (ADD0)
unnamed: R406.1, R407.2, U403.4 (ADD0)
unnamed: R411.2, U404.1 (ADDR)
unnamed: C402.1, R409.2, U404.5 (AIN1)
unnamed: C405.1, R410.2, U404.6 (AIN2)
unnamed: C406.1, R414.2, U404.7 (AIN3)

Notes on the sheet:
- I2C-ADDRESS: 1001000 - 860 SPS, input multiplexer - PGA: +-256 mV .. +-6.144V
Address, check Table 6-4 - One ADD0 high - One with ADD0 low Pull-ups - SDA, SCL: open-drain LED - Vf: 2 V, I = 1.2 mA (when ok)
PWM CONNECTORS
CURRENT MEASUREMENT
ADC: - Z_hall_src = 0.2-2 Ohm - 16-bit accuracy: Vrange / (2**(16-1)) - I_in_max = 7.5 A, Vo_max = 7.5 * 0.2 = 1.5 V - Z_ADC_diff = 2.4 MOhm (at 1.024 V) [Assume average current won't be much larger] - Vin: (-1.024, 1.024) V, 200 mV / A - Accuracy: 31.25 uV -> 31.25 / 200 = 0.156 mA - I_in_max = 11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
TEMPERATURE REGULATION
- R-divider: ratio 0.0099 - Vmax: 25 V -> 2.064 V - Pmax: 62.5 mW - 25 V / 22e3 Ohm = 1.2 mA - 20e3 * (1.2e-3)**2 = 28.8 mW
Pins: - SDA, SCL (2) + gnd (2) - PWM (4) + GND (4) - BOOST_EN + SEPIC_EN (2) (basically DC so no ground needed here) So: 8 pins with ground connected
VBATT MEASUREMENT
ADDRESS: 1001001
ADDRESS: 1001011

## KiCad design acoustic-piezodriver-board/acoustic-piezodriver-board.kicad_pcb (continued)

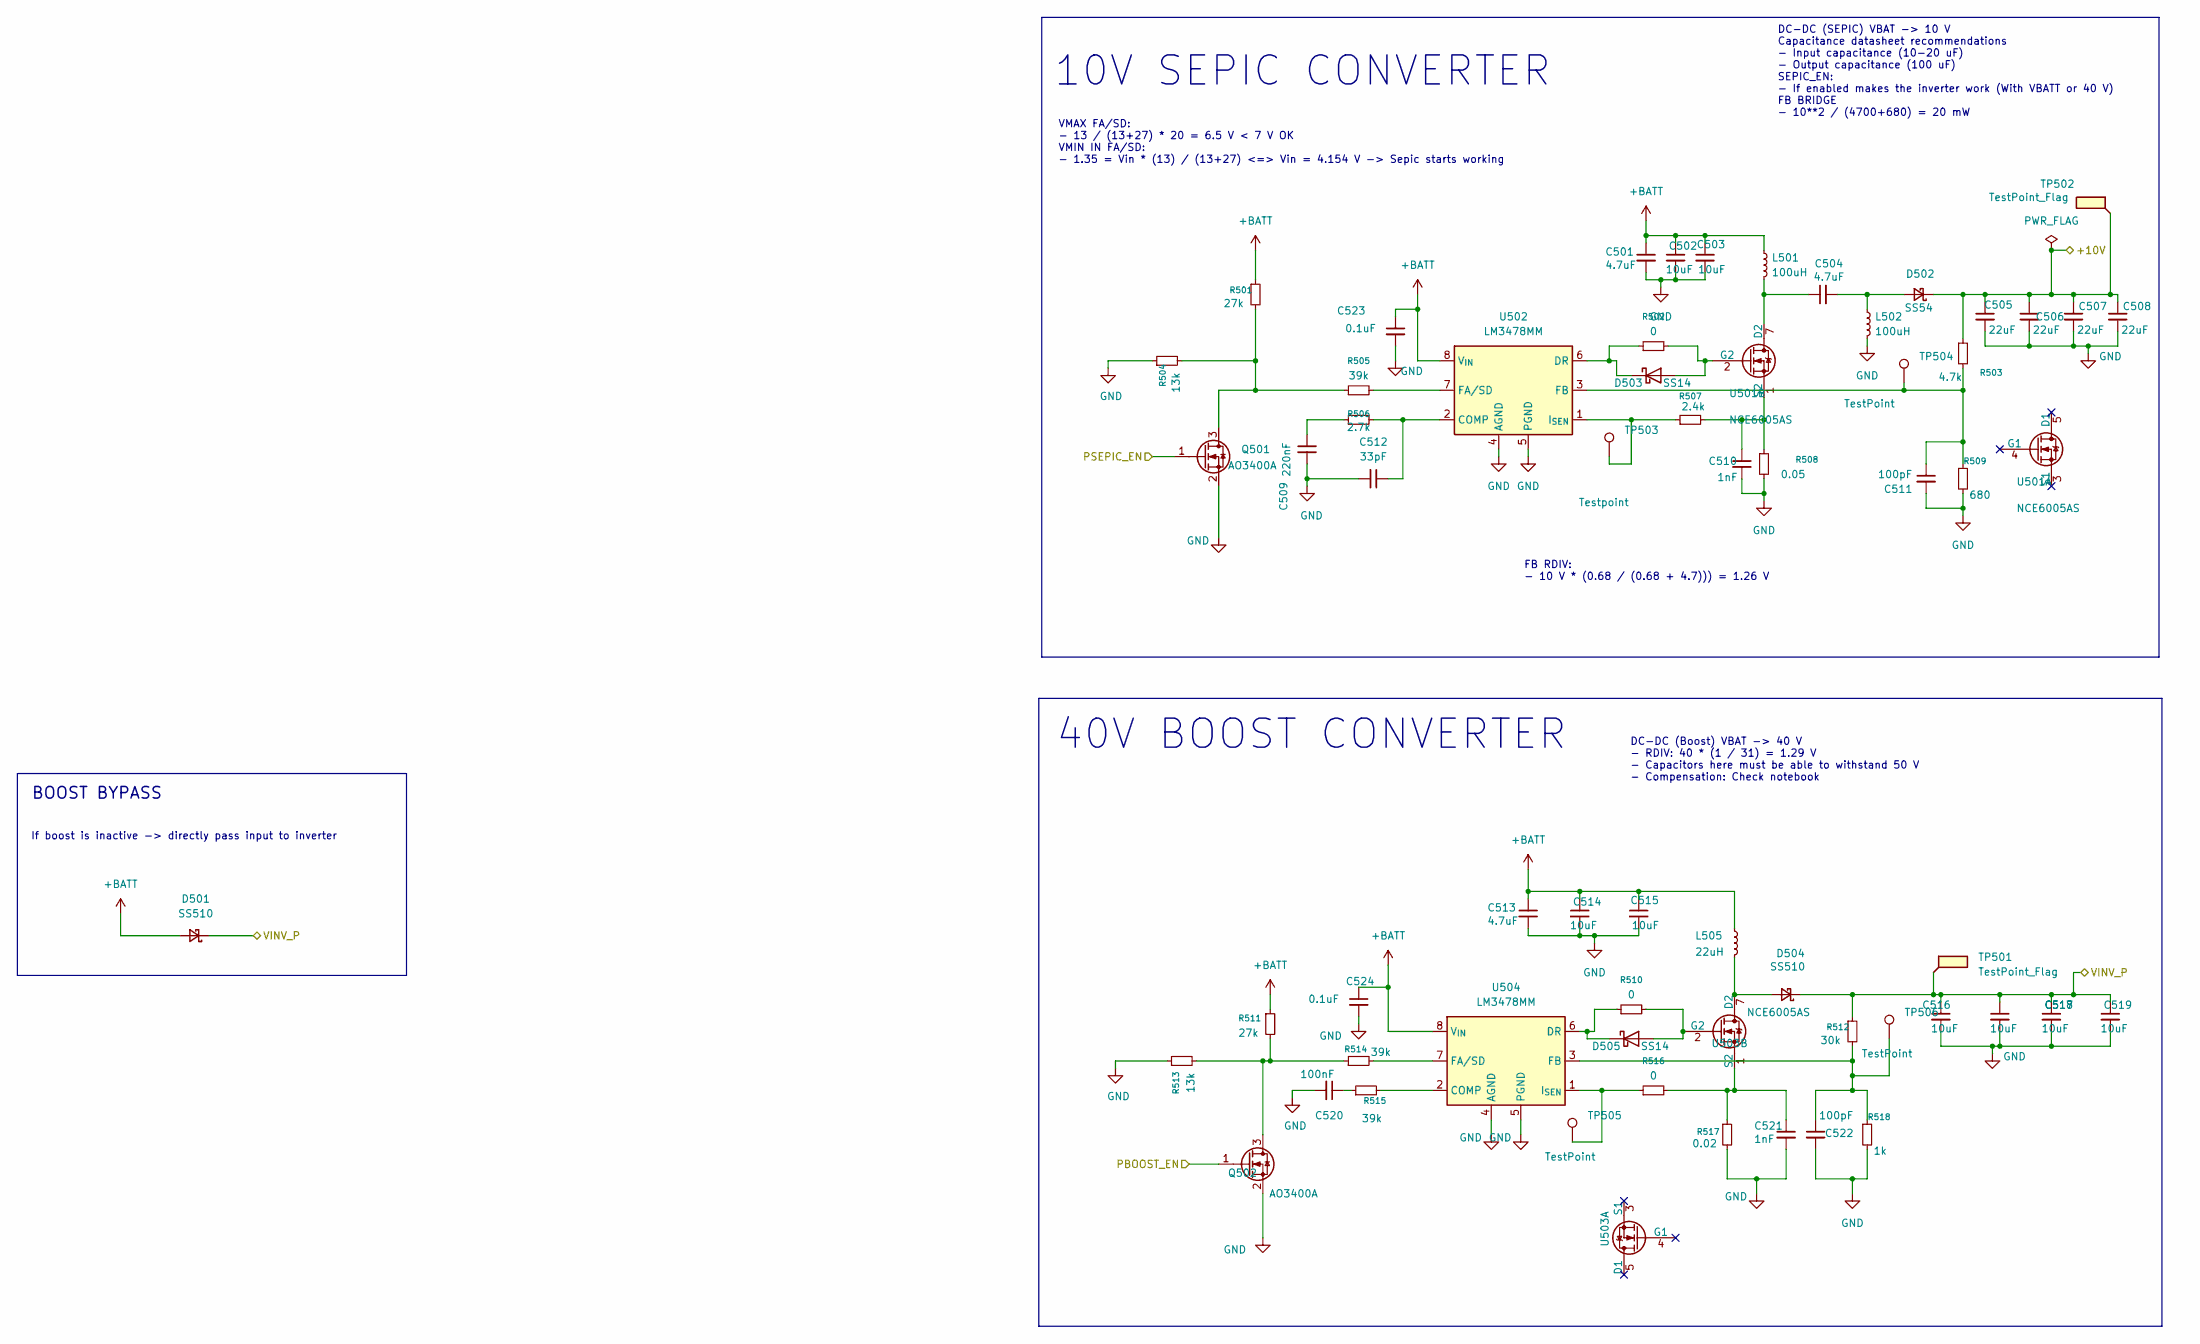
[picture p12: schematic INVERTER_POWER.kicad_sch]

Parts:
C501, C504, C513: 4.7uF; C_1206_3216Metric; Manufacturing Part Numb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 1206B475K500NT; LCSC Part Number C29823
C502, C503, C514, C515, C516, C517, C518, C519: 10uF; C_0805_2012Metric; Manufacturing Part Numb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 GRM21BR61H106KE43L; LCSC Part Number C440198
C505, C506, C507, C508: 22uF; C_0805_2012Metric; Manufacturing Part Numb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 CL21A226MAQNNNE; LCSC Part Number C45783
C509: 220nF; C_0805_2012Metric; Manufacturing Part Numb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 CL21B224KBFNNNE; LCSC Part Number C5378
C510, C521: 1nF; C_0402_1005Metric; Manufacturing Part Numb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 0402B102K500NT; LCSC Part Number C1523
C511, C522: 100pF; C_0402_1005Metric; Manufacturing Part Numb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 0402CG101J500NT; LCSC Part Number C1546
C512: 33pF; C_0603_1608Metric; Manufacturing Part Numb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 CL10C330JB8NNNC; LCSC Part Number C1663
C520: 100nF; C_0603_1608Metric; Manufacturing Part Numb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 CC0603KRX7R9BB104; LCSC Part Number C14663
C523, C524: 0.1uF; C_0402_1005Metric; Manufacturing Part Numb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 CL05B104KB54PNC; LCSC Part Number C307331
D501, D504: SS510; D_SMA; Manufacturing Part Numb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 SS510; LCSC Part Number C65010
D502: SS54; D_SMA; Manufacturing Part Numb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 SS54; LCSC Part Number C22452
D503, D505: SS14; D_SMA; Manufacturing Part Numb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 SS14; LCSC Part Number C2480
L501, L502: 100uH; PSPMAA1050H-101M-ANP; Manufacturing Part Numb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 PSPMAA1050H-101M-ANP; LCSC Part Number C5273830
L505: 22uH; PA4343.223NLT; Manufacturing Part Numb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 PA4343.223NLT; LCSC Part Number C2453841
Q501, Q502: AO3400A; SOT-23; Manufacturing Part Numb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 AO3400A; LCSC Part Number C20917
R501, R511: 27k; R_0603_1608Metric; Manufacturing Part Numb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 0603WAF2702T5E; LCSC Part Number C22967
R502, R510, R516: 0; R_0603_1608Metric_Pad0.98x0.95mm_HandSolder; Manufacturing Part Numb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 0603WAJ0000T5E; LCSC Part Number C15402
R503: 4.7k; R_0603_1608Metric; Manufacturing Part Numb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 0603WAF4701T5E; LCSC Part Number C23162
R504, R513: 13k; R_0603_1608Metric; Manufacturing Part Numb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 0603WAF1302T5E; LCSC Part Number C22797
R505, R514, R515: 39k; R_0603_1608Metric; Manufacturing Part Numb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 0603WAF3902T5E; LCSC Part Number C23153
R506: 2.7k; R_0603_1608Metric; Manufacturing Part Numb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 0603WAF2701T5E; LCSC Part Number C13167
R507: 2.4k; R_0805_2012Metric_Pad1.20x1.40mm_HandSolder; Manufacturing Part Numb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 0805W8F2401T5E; LCSC Part Number C17526
R508: 0.05; R_1206_3216Metric_Pad1.30x1.75mm_HandSolder; Manufacturing Part Numb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 1206W3F500MT5E; LCSC Part Number C127691
R509: 680; R_0603_1608Metric; Manufacturing Part Numb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 0603WAF6800T5E; LCSC Part Number C23228
R512: 30k; R_0603_1608Metric; Manufacturing Part Numb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 0603WAF3002T5E; LCSC Part Number C22984
R517: 0.02; R_1206_3216Metric_Pad1.30x1.75mm_HandSolder; Manufacturing Part Numb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 1206W3F200MT5E; LCSC Part Number C2765435
R518: 1k; R_0603_1608Metric; Manufacturing Part Numb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 0603WAF1001T5E; LCSC Part Number C21190
TP501, TP502: TestPoint_Flag; TestPoint_THTPad_D4.0mm_Drill2.0mm
TP503: Testpoint; TestPoint_Pad_D1.0mm
TP504, TP505, TP506: TestPoint; TestPoint_Pad_D1.0mm
U501, U503: NCE6005AS; SOIC-8_3.9x4.9mm_P1.27mm; Manufacturing Part Numb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 NCE6005AS; LCSC Part Number C126151
U502, U504: LM3478MM; VSSOP-8_3x3mm_P0.65mm; Manufacturing Part Numb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 LM3478MMX/NOPB; LCSC Part Number C404045

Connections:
+BATT: C501.1, C502.1, C503.1, C513.1, C514.1, C515.1, C523.1, C524.1, D501.2 (A), L501.1, L505.1, R501.1, R511.1, U502.8 (V_{IN}), U504.8 (V_{IN}); also elsewhere on the board
/INVERTER/+10V: C505.1, C506.1, C507.1, C508.1, D502.1 (K), R503.1, TP502.1; also elsewhere on the board
/INVERTER/PBOOST_EN: Q502.1 (G); also elsewhere on the board
/INVERTER/PSEPIC_EN: Q501.1 (G); also elsewhere on the board
/INVERTER/VINV_P: C516.1, C517.1, C518.1, C519.1, D501.1 (K), D504.1 (K), R512.1, TP501.1; also elsewhere on the board
GND: C501.2, C502.2, C503.2, C505.2, C506.2, C507.2, C508.2, C509.2, C510.2, C511.2, C512.2, C513.2, C514.2, C515.2, C516.2, C517.2, C518.2, C519.2, C520.2, C521.2, C522.2, C523.2, C524.2, L502.2, Q501.2 (S), Q502.2 (S), R504.1, R508.2, R509.2, R513.1, R517.2, R518.2, U502.4 (AGND), U502.5 (PGND), U504.4 (AGND), U504.5 (PGND); also elsewhere on the board
unnamed: C504.1, L501.2, U501.7 (D2), U501.8 (D2)
unnamed: C509.1, R506.1
unnamed: C520.1, R515.1
unnamed: C504.2, D502.2 (A), L502.1
unnamed: D503.2 (A), R502.2, U501.2 (G2)
unnamed: D503.1 (K), R502.1, U502.6 (DR)
unnamed: D504.2 (A), L505.2, U503.7 (D2), U503.8 (D2)
unnamed: D505.2 (A), R510.2, U503.2 (G2)
unnamed: D505.1 (K), R510.1, U504.6 (DR)
unnamed: Q501.3 (D), R501.2, R504.2, R505.1
unnamed: Q502.3 (D), R511.2, R513.2, R514.1
unnamed: C510.1, R507.2, R508.1, U501.1 (S2)
unnamed: C512.1, R506.2, U502.2 (COMP)
unnamed: R505.2, U502.7 (FA/SD)
unnamed: C511.1, R503.2, R509.1, TP504.1, U502.3 (FB)
unnamed: R507.1, TP503.1, U502.1 (I_{SEN})
unnamed: C521.1, R516.2, R517.1, U503.1 (S2)
unnamed: R515.2, U504.2 (COMP)
unnamed: R514.2, U504.7 (FA/SD)
unnamed: C522.1, R512.2, R518.1, TP506.1, U504.3 (FB)
unnamed: R516.1, TP505.1, U504.1 (I_{SEN})

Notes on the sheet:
DC-DC (Boost) VBAT -> 40 V - RDIV: 40 * (1 / 31) = 1.29 V - Capacitors here must be able to withstand 50 V - Compensation: Check notebook
DC-DC (SEPIC) VBAT -> 10 V Capacitance datasheet recommendations - Input capacitance (10-20 uF) - Output capacitance (100 uF) SEPIC_EN: - If enabled makes the inverter work (With VBATT or 40 V) FB BRIDGE - 10**2 / (4700+680) = 20 mW
10V SEPIC CONVERTER
FB RDIV: - 10 V * (0.68 / (0.68 + 4.7))) = 1.26 V
40V BOOST CONVERTER
VMAX FA/SD: - 13 / (13+27) * 20 = 6.5 V < 7 V OK VMIN IN FA/SD: - 1.35 = Vin * (13) / (13+27) <=> Vin = 4.154 V -> Sepic starts working
If boost is inactive -> directly pass input to inverter
BOOST BYPASS

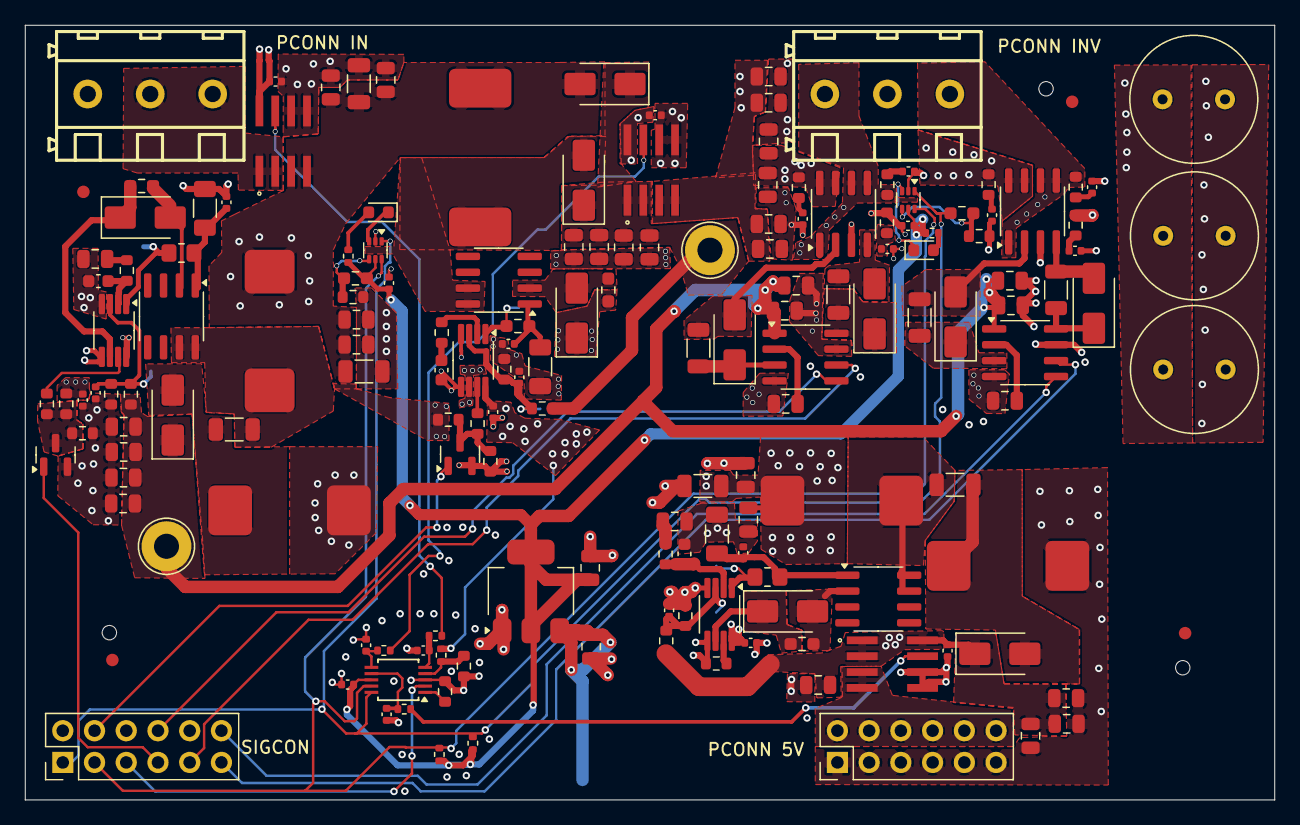
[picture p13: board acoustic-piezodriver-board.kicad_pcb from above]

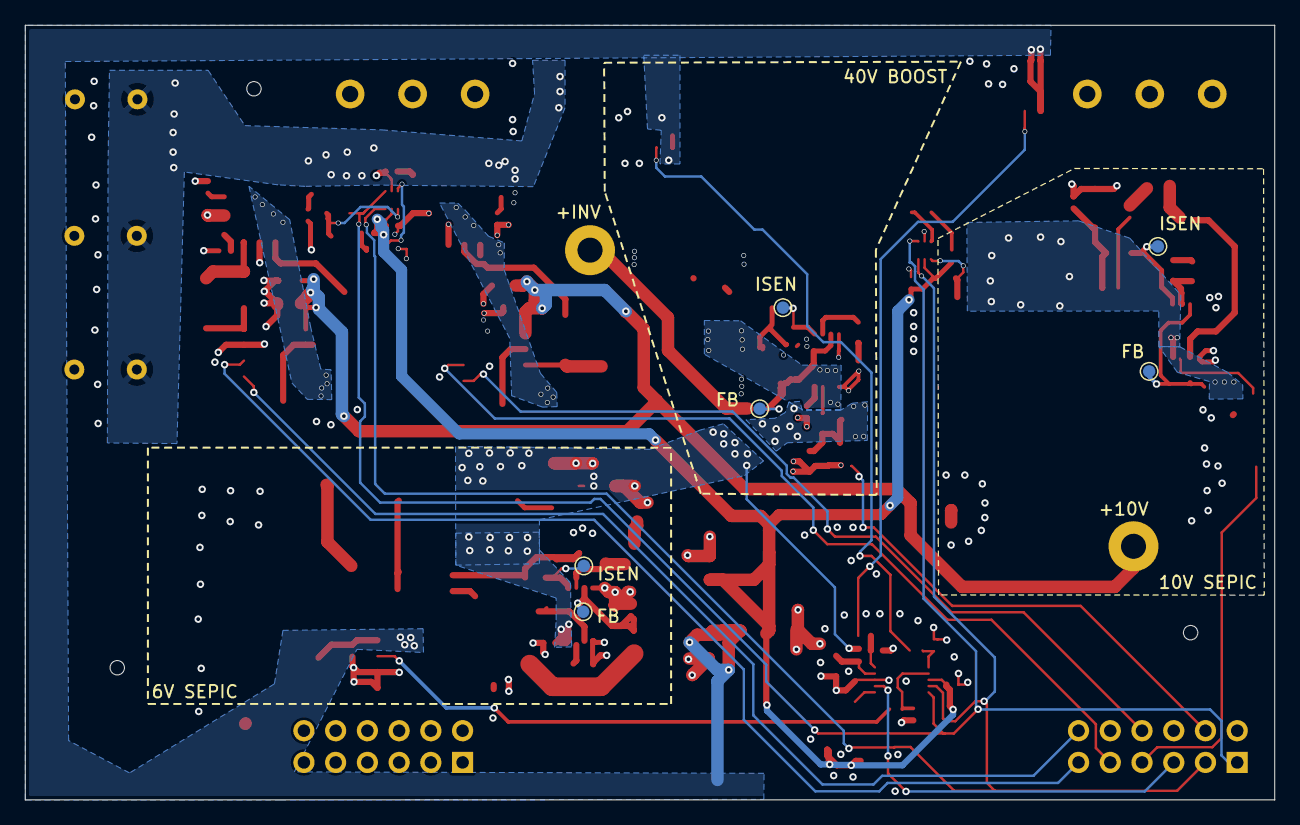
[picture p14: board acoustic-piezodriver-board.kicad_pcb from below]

Board: 4 copper layers, 100.0 x 62.0 mm, 174 parts (6 on the bottom side), 81 nets.

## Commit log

2025-07-28 [acoustic-processing-board] Added board as submodule
    [JLC3313_6L.FCStd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]
2025-07-28 stripped down repo to piezodriver board only
    [COMPUTE_POWER.kicad_sch, INVERTER_POWER.kicad_sch, SENSORS.kicad_sch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]
2025-07-29 [schematic] added adc for temperature measurement, current sense resistors, [layout] component placement, connector placement
    [INVERTER_POWER.kicad_sch, acoustic-piezodriver-board.kicad_pcb, acoustic-piezodriver-board.kicad_sch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]
2025-07-29 [piezodriver] Added resistive divider (next) come up with a solution for current sensing (galvanic isolation?)
    [INVERTER_POWER.kicad_sch, sensor_conn.kicad_sch]
2025-07-30 found hal-sensor, replaced with different one for lower voltage signal source impedance, reorganised schematic
    [INVERTER_POWER.kicad_sch, acoustic-piezodriver-board.kicad_sch, compute_power.kicad_sch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]
2025-07-30 added new notes + schematic component hal sensors
    [INVERTER_POWER.kicad_sch, acoustic-piezodriver-board.kicad_sch, compute_power.kicad_sch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]
2025-07-31 finished schematic, routing
    [INVERTER_POWER.kicad_sch, acoustic-piezodriver-board.kicad_pcb, acoustic-piezodriver-board.kicad_sch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]
2025-07-31 replaced dual 10uH inductors with single 22uH higher VDC resistant one, started laying out 40 V boost
    [INVERTER_POWER.kicad_sch, acoustic-piezodriver-board.kicad_pcb, acoustic-piezodriver-board.kicad_sch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]
2025-07-31 placed inverter and 40 V boost (next) place 10 V SEPIC driver
    [INVERTER_POWER.kicad_sch, acoustic-piezodriver-board.kicad_pcb, compute_power.kicad_sch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]
2025-07-31 rough layout completed, reduce board size and place components accordingly
    [INVERTER_POWER.kicad_sch, acoustic-piezodriver-board.kicad_pcb]
2025-08-01 completed positioning (next) routing
    [acoustic-piezodriver-board.kicad_pcb, inverter.kicad_sch]
2025-08-02 Did partial layout of inverter + 40 V boost + 10 V buck (next) Finish inverter, reorder and route SEPIC, check I2C bus capacitance limit
    [acoustic-piezodriver-board.kicad_pcb, acoustic-piezodriver-board.kicad_sch]
2025-08-04 main routing completed, finish 3V3 + I2C bus
    [acoustic-piezodriver-board.kicad_pcb, inverter.kicad_sch]
2025-08-05 completed 3V3 routing
    [acoustic-piezodriver-board.kicad_pcb]
2025-08-06 Fixed ERC, DRC errors, finished routing (next) perform footprint checks
    [INVERTER_POWER.kicad_sch, acoustic-piezodriver-board.kicad_pcb, acoustic-piezodriver-board.kicad_sch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]
2025-08-10 changed footprints, changed stackup from L3:PWR-> L3:GND and routed +BATT on 4th layer
    [INVERTER_POWER.kicad_sch, acoustic-piezodriver-board.kicad_pcb, compute_power.kicad_sch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]
2025-08-10 [production checks] checked caps, [todo] Think about replacing 220 nF filtering caps in DC-DC to 0402 package (next) check rest of footprints
    [INVERTER_POWER.kicad_sch, acoustic-piezodriver-board.kicad_pcb, acoustic-piezodriver-board.kicad_sch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]
2025-08-11 changed ss520 footprints
    [INVERTER_POWER.kicad_sch, acoustic-piezodriver-board.kicad_pcb, compute_power.kicad_sch]
2025-08-12 checked components until mosfets
    [INVERTER_POWER.kicad_sch, acoustic-piezodriver-board.kicad_pcb, compute_power.kicad_sch]
2025-08-12 completed footprint check (next) reroute pbootstrap circuit on top layer only, fix errors after footprint change
    [INVERTER_POWER.kicad_sch, acoustic-piezodriver-board.kicad_pcb, compute_power.kicad_sch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]
2025-08-13 Modified feedback path for low-impedance signals tobe closer to FB pin
    [acoustic-piezodriver-board.kicad_pcb]
2025-08-15 fixed erc and drc errors completely, added 3d models for connectors, finished DFM (next) create gerbers, check
    [INVERTER_POWER.kicad_sch, acoustic-piezodriver-board.kicad_pcb, compute_power.kicad_sch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]
2025-08-16 added testpoints on fb and isense pins (next) double-check schematic and order
    [INVERTER_POWER.kicad_sch, acoustic-piezodriver-board.kicad_pcb, acoustic-piezodriver-board.kicad_sch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]
2025-08-17 added gerbers
    [INVERTER_POWER.kicad_sch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]
2025-08-23 added lower side box for PCB
    [piezodriver_case.FCStd]
2025-08-25 added case changes
    [acoustic-piezodriver-board-B_Cu.gbl, acoustic-piezodriver-board-B_Mask.gbs, acoustic-piezodriver-board-B_Paste.gbp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]
2025-09-04 Build box bottom (next) build box lid
    [case_2.FCStd, piezodriver_case.FCStd]
2025-09-05 completed design (next) trying to 3D print M3-M4 thread
2025-09-07 minor change
    [acoustic-piezodriver-board.kicad_sch]
2025-09-07 added driver-board-testcode
